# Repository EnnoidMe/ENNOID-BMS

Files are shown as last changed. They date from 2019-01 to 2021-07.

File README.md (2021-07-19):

# ENNOID - BMS

ENNOID-BMS is an open-source configurable battery management system consisting of a Master board based on an STM32 microcontroller connected through an ISOSPI interface to several modular slave boards. ENNOID-BMS can monitor the specifics temperatures, currents & voltages that are critical for any lithium-ion battery packs. Based on the monitored inputs & the configured parameters, the master board can allow or interrupt the flow of energy from the battery pack by switching the state of external heavy-duty contactors. ENNOID-BMS can measure each cell voltage level & can trigger the passive balancing function during charging for cells above the configured limit to ensure that all cells have a similar State-Of-Charge (SOC). Parameters can be configured through the ENNOID-BMS-Tool software running on a USB connected host computer.

## Ordering:

For ordering assembled BMS or battery packs, please visit:

https://www.ennoid.me/bms/gen-1

## Documentation:
https://blog.ennoid.me/

## Block diagram

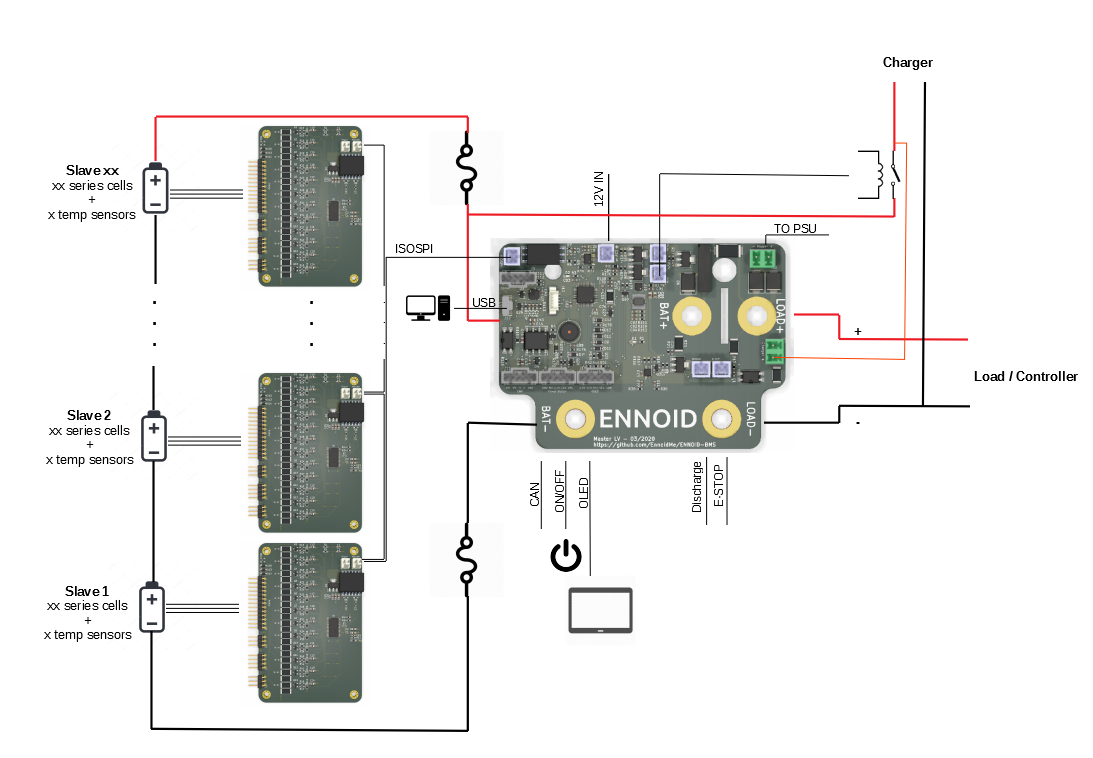
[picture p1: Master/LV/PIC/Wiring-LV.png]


The evolution of the BMS can be followed on this thread:

https://endless-sphere.com/forums/viewtopic.php?f=14&t=92952

## Features:

- Modular with master/slave topology
- 12S, 15S & 18S slaves board options
- Master board options: High Voltage (Master-HV) & Low voltage (Master-LV)
- Up to 500A continuous operation
- Integrated bi-directional current sensor
- 12V drive coil outputs for charge,  discharge & auxiliary circuits
- Communication between slaves & master through a two-wire daisy chained ISOSPI interface
- Isolated CAN bus interface 
- Isolated charger detection circuit
- Voltage measurement for battery pack & load
- Build-in precharge circuits
- USB interface for programming and firmware upgrades through an easy to use graphical user interface
- OLED Display, serial output & power button
- 0V to 5V cell voltage operation

## Documentation:

[ENNOID-BMS Datasheet](https://github.com/EnnoidMe/ENNOID-BMS/blob/master/Datasheet.pdf)

## Software:

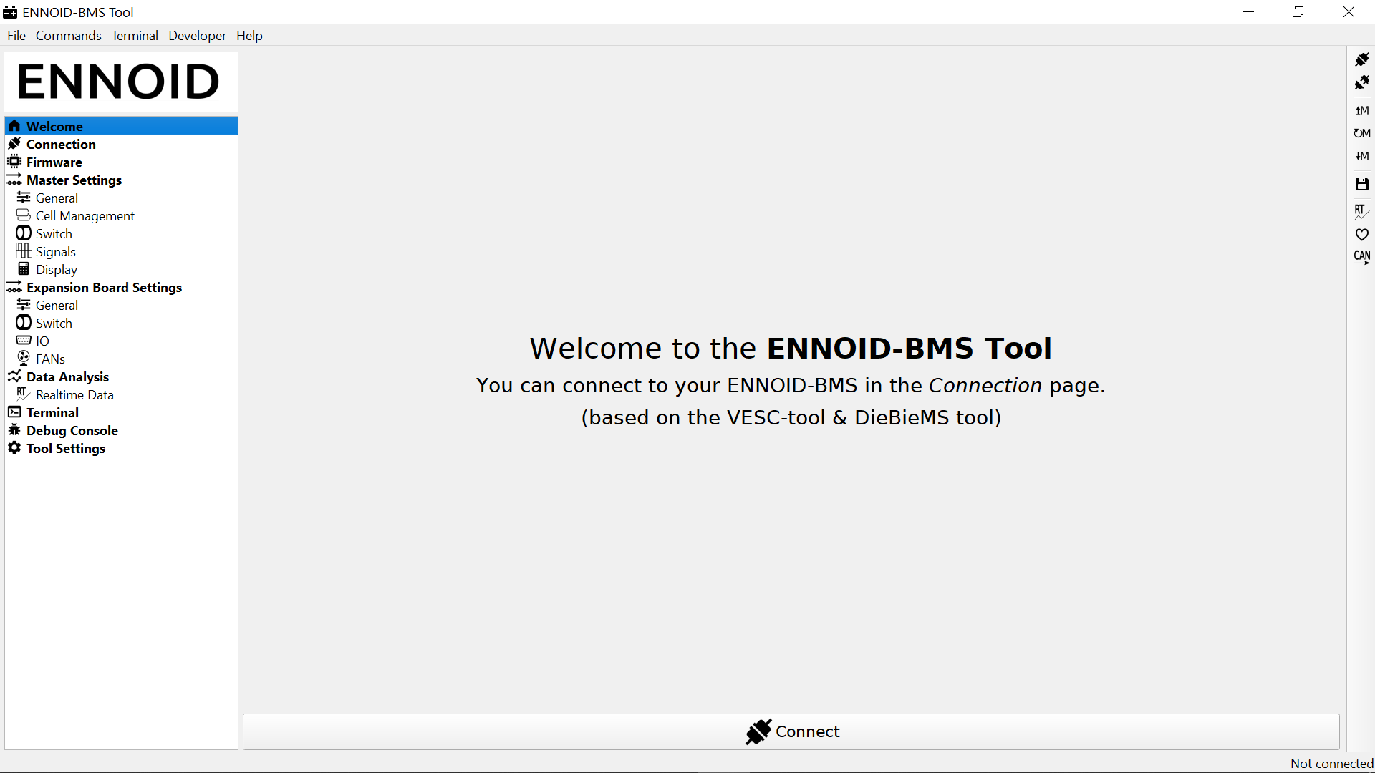
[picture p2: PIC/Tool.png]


ENNOID-BMS GUI configuration tool:
[ENNOID-BMS tool](https://github.com/EnnoidMe/ENNOID-BMS-Tool)

## Firmware:

ENNOID-BMS firmware .bin file:
[ENNOID-BMS.bin](https://github.com/EnnoidMe/ENNOID-BMS-Firmware)

View this project on [CADLAB.io](https://cadlab.io/project/1987).

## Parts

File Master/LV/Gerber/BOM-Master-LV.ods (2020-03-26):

ID | Part | Footprint | MPN | QTY
BZ1 | AI-1027-TWT-5V | ENNOID:BUZZER | AI-1027-TWT-5V-2-R | 1
> C6, C7 | 10n | Capacitor_SMD:C_0603_1608Metric | GRM188R71H103KA01D | 2
C20 | 1u | Capacitor_SMD:C_0603_1608Metric | GRM188R71E105KA12D | 1
> C39, C40, C42, C88 | 2.2u | Capacitor_SMD:C_0603_1608Metric | GRM188R61A225KE34D | 4
> C1, C8, C11, C41, C44, C47, C71-C73, C78, C80-C84 | 100n | Capacitor_SMD:C_0603_1608Metric | GRM188R71E104KA01D | 15
> C43, C46 | 1u | Capacitor_SMD:C_0805_2012Metric | GRM188R71E105KA12D | 2
C45 | 10n | Capacitor_SMD:C_0805_2012Metric | GRM188R71H103KA01D | 1
> C76, C77 | 18p | Capacitor_SMD:C_0603_1608Metric | GRM1885C1H180JA01D | 2
> C89, C90 | 22u | Capacitor_SMD:C_0805_2012Metric | CL21A226MOQNNNE | 2
C91 | 47n | Capacitor_SMD:C_0603_1608Metric | GCM188R71H473KA55D | 1
> C92-C94 | 10u | Capacitor_SMD:C_0603_1608Metric | CL10A106MQ8NNNC | 3
D1 | POWER | LED_SMD:LED_0603_1608Metric | SML-D12P8WT86C | 1
D2 | STATUS | LED_SMD:LED_0603_1608Metric | SML-D12P8WT86C | 1
D3 | SP0502BAHT | TO_SOT_Packages_SMD:SOT-23 | SP0502BAHTG | 1
D4 | SZNUP2105L | TO_SOT_Packages_SMD:SOT-23 | SZNUP2105LT1G | 1
D5 | smcj150ca | Diode_SMD:D_SMC |  | 1
> D7, D10 | BZT52C16 | Diodes_SMD:D_SOD-123 | BZT52C16-E3-08 | 2
> D8, D9, D11-D13 | 1N4148W | Diodes_SMD:D_SOD-123 | 1N4148W-7-F | 5
K1 | HE3621A1200 | ENNOID:HE3621A1200 | HE3621A1200 | 1
L3 | 744043151 | Inductors_SMD:L_Wuerth_WE-PD2-Typ-MS | 744043151 | 1
> Q1, Q3, Q26-Q30 | BSS138 | TO_SOT_Packages_SMD:SOT-23 | BSS138 | 7
> Q4-Q7 | BUK98150-55A | Package_TO_SOT_SMD:SOT-223 | BUK98150-55A/CUF | 4
> R1-R3 | 470 | Resistor_SMD:R_0603_1608Metric | RC0603JR-07470RL | 3
R4 | 1.5k | Resistor_SMD:R_0603_1608Metric | RC0603JR-071K5L | 1
R5 | 806 | Resistor_SMD:R_0603_1608Metric | RC0603JR-071K2L | 1
> R6, R7 | 51 | Resistor_SMD:R_0603_1608Metric | RC0603JR-0751RL | 2
R9 | 100k | Resistor_SMD:R_2512_6332Metric | RC2512FK-07100KL | 1
R11 | 10k | Resistor_SMD:R_2512_6332Metric | 25121WJ0103T4E | 1
> R16, R20 | 220k | Resistor_SMD:R_2512_6332Metric | 25121WF2203T4E | 2
> R21, R170 | 100k | Resistor_SMD:R_0603_1608Metric | RC0603JR-07100KL | 2
> R23-R25, R32 | 10 | Resistor_SMD:R_0603_1608Metric | RC0603JR-0710RL | 4
R29 | CSM2F-8518-L100J01 | ENNOID:CSM2F-8518-L100J01 | CSM2F-8518-L100J01 | 1
R36 | 1.2k | Resistor_SMD:R_0603_1608Metric | RC0603FR-07806RL | 1
> R17, R42, R46, R50, R166, R167 | 4.75k | Resistor_SMD:R_0603_1608Metric | RC0603JR-074K7L | 6
> R111, R112 | 240 | Resistor_SMD:R_0603_1608Metric | RC0603FR-07240RL | 2
> R19, R113, R114, R168, R173, R176, R178 | 10k | Resistor_SMD:R_0603_1608Metric | RMCF2512JT10K0 | 7
R115 | 4.7M | Resistor_SMD:R_0805_2012Metric | RC0805JR-0710ML | 1
> R37, R116 | 2.2k | Resistor_SMD:R_0603_1608Metric | RC0603JR-072K2L | 2
> R35, R38, R172 | 100 | Resistor_SMD:R_0603_1608Metric | RC0603FR-07100RL | 3
R174 | 1M | Resistor_SMD:R_0603_1608Metric | RC0603JR-071ML | 1
> R8, R27, R28, R33, R175, R177 | 4.7M | Resistor_SMD:R_0603_1608Metric | RC0603FR-074M7L | 6
R179 | 130k | Resistor_SMD:R_0603_1608Metric | RC0603FR-07130KL | 1
> R180-R182 | 1 | Resistor_SMD:R_0603_1608Metric | RC0603FR-071RL | 3
TH1 | Thermistor_NTC 100k | Resistor_SMD:R_0805_2012Metric | SDNT2012X104F4250FTF | 1
TR2 | HM2108NL | ENNOID:HM2108NL | HM2108NL | 1
U1 | ISL28022 | Package_SO:VSSOP-10_3x3mm_P0.5mm | ISL28022FUZ-T7A | 1
U2 | LTC6820 | Housings_SSOP:MSOP-16_3x4mm_Pitch0.5mm | LTC6820IMS#PBF | 1
U5 | SFH617A-2X009T | Housings_DIP:SMDIP-4_W9.53mm_Clearance8mm | SFH617A-2X009T | 1
U7 | CP2104 | Housings_DFN_QFN:QFN-24-1EP_4x4mm_Pitch0.5mm | CP2104-F03-GM | 1
U8 | ISO1050DUBR | ENNOID:ISO1050 | ISO1050DUBR | 1
U9 | SFH617A-2X017T | Housings_DIP:SMDIP-4_W9.53mm_Clearance8mm | SFH617A-2X009T | 1
U17 | STM32F303CCTx | Housings_QFP:LQFP-48_7x7mm_Pitch0.5mm | STM32F303CCT6 | 1
U19 | LM5165YDRC | Housings_SON:Texas_S-PVSON-N10_ThermalVias | LM5165YDRCT | 1
Y1 | 8MHz | Crystals:Crystal_SMD_Abracon_ABM3-2pin_5.0x3.2mm | ABM3-8.000MHZ-D2Y-T | 1

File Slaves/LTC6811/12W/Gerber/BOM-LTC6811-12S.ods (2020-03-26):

ID | Part | Footprint | MPN | QTY
> C1, C2, C5, C25, C26 | 1u | Capacitor_SMD:C_0805_2012Metric | CL21B105KBFNNNE | 5
> C3, C4, C8-C24 | 100n | Capacitor_SMD:C_0603_1608Metric | CC0603KRX7R0BB104 | 19
> C6, C7 | 100p | Capacitor_SMD:C_0603_1608Metric | CL10C101JB8NNNC | 2
> D1-D12 | PDZ7.5B | Diode_SMD:D_SOD-323 | PDZ7.5BZ | 12
> D13, D14 | 1N4148W | Diode_SMD:D_SOD-123 | 1N4148W-7-F | 2
D15 | BZT52H-C62 | Diode_SMD:D_SOD-123 | BZT52H-C62,115 | 1
D16 | LED | LED_SMD:LED_0603_1608Metric | SML-D12P8WT86C | 1
> F1-F13 | 0.25A | ENNOID:FUSE | N/A | 13
FB1 | 33 | Resistor_SMD:R_0603_1608Metric | BLM18PG330SN1D | 1
J1 | Cells | Pin_Headers:Pin_Header_Angled_1x13_Pitch2.54mm | N/A | 1
J2 | PB MB | ENNOID:Pin_1x02-XL | 70543-0001 | 1
J3 | PA MA | ENNOID:Pin_1x02-XL | 70543-0001 | 1
J4 | Temp | Connector_PinHeader_2.54mm:PinHeader_1x05_P2.54mm_Horizontal | N/A | 1
> J5-J8 | Conn_01x01 | Mounting_Holes:MountingHole_3.2mm_M3_ISO7380_Pad | N/A | 4
LOGO1 | Logo_Open_Hardware_Small | ENNOID:ENNOID-LOGO | N/A | 1
Q1 | NSV1C201MZ4 | TO_SOT_Packages_SMD:SOT-223 | NSV1C201MZ4T1G | 1
> Q2-Q13 | TSM2323 | TO_SOT_Packages_SMD:SOT-23 | TSM2323CX RFG | 12
> R3, R10 | 1.2k | Resistor_SMD:R_0603_1608Metric | RC0603JR-071K2L | 2
R4 | 806 | Resistor_SMD:R_0603_1608Metric | RC0603FR-07806RL | 1
> R1, R2, R5, R6, R13, R16, R19, R22, R25, R28, R31, R34, R37, R40, R43, R46 | 100 | Resistor_SMD:R_0603_1608Metric | RC0603FR-07100RL | 16
R7 | 1M | Resistor_SMD:R_0603_1608Metric | RC0603JR-071ML | 1
> R8, R9 | 0 | Resistor_SMD:R_0603_1608Metric | RC0603JR-070RL | 2
> R11, R60-R63 | 100k | Resistor_SMD:R_0603_1608Metric | RC0603JR-07100KL | 5
> R12, R15, R18, R21, R24, R27, R30, R33, R36, R39, R42, R45 | 36 | Resistor_SMD:R_2512_6332Metric | RTT25360JTE | 12
> R14, R17, R20, R23, R26, R29, R32, R35, R38, R41, R44, R47 | 3.3k | Resistor_SMD:R_0603_1608Metric | RC0603JR-073K3L | 12
TH1 | 100k | Resistor_SMD:R_0805_2012Metric | SDNT2012X104F4250FTF | 1
TR1 | HM2102NL | ENNOID:HM2102NL | HM2102NLT | 1
U1 | LTC6811-1 | Housings_SSOP:TSSOP-48_6.1x12.5mm_Pitch0.5mm | LTC6811HG-1#PBF | 1

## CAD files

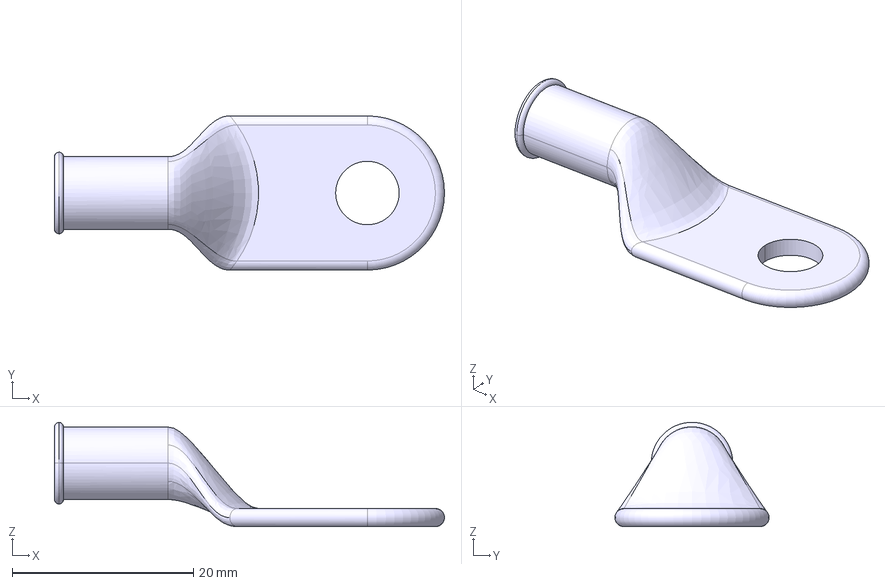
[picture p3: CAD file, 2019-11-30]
Master/LV/PCB/CAD/Copper_Lug.stp
43.0 x 17.0 x 11.5 mm

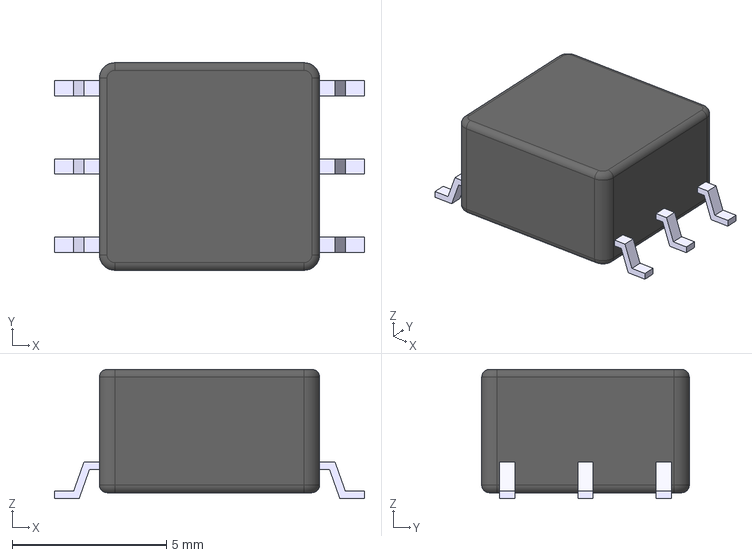
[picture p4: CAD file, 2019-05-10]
Master/LV/PCB/CAD/WURTH-760390014.stp
10.1 x 6.73 x 4.19 mm

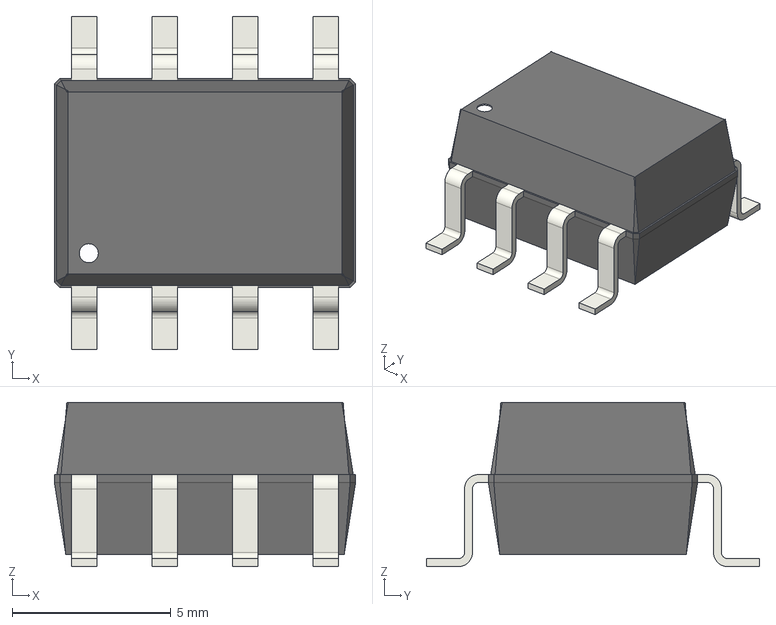
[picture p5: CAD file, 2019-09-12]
Master/HV/PCB/CAD/soic_8_66x95_p254.step
9.50 x 10.5 x 5.18 mm

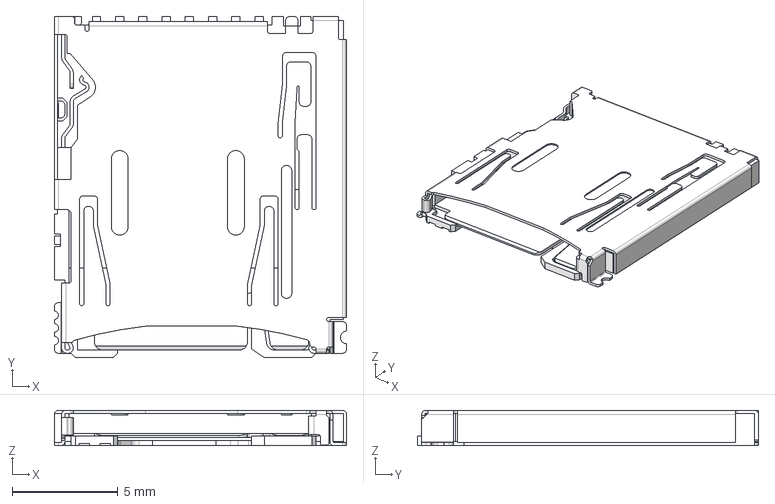
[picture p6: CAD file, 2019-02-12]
Master/LV/PCB/CAD/DM3AT-SF-PEJM5.stp
13.8 x 16.2 x 1.68 mm

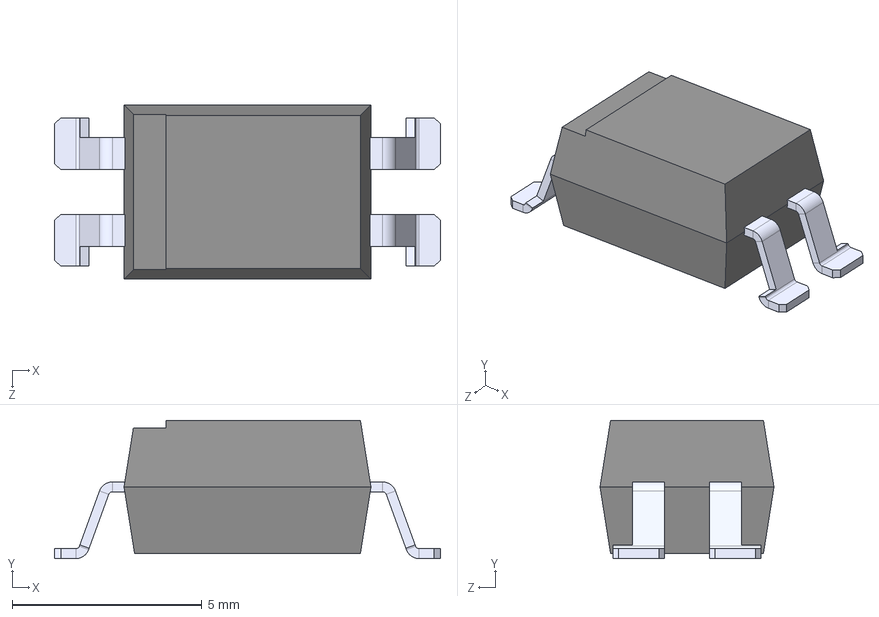
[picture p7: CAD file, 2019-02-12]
Master/LV/PCB/CAD/DIP4-OP9.STEP
10.2 x 3.64 x 4.58 mm

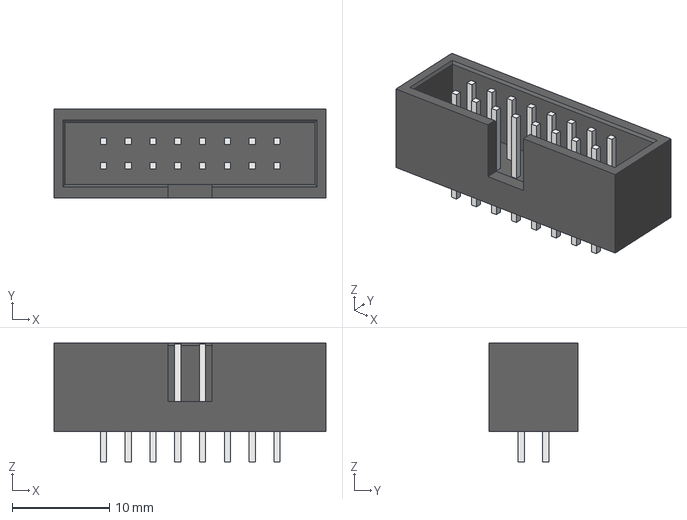
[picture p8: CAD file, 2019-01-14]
Master/LV/PCB/CAD/CONN 2X8.step
27.9 x 9.10 x 12.2 mm

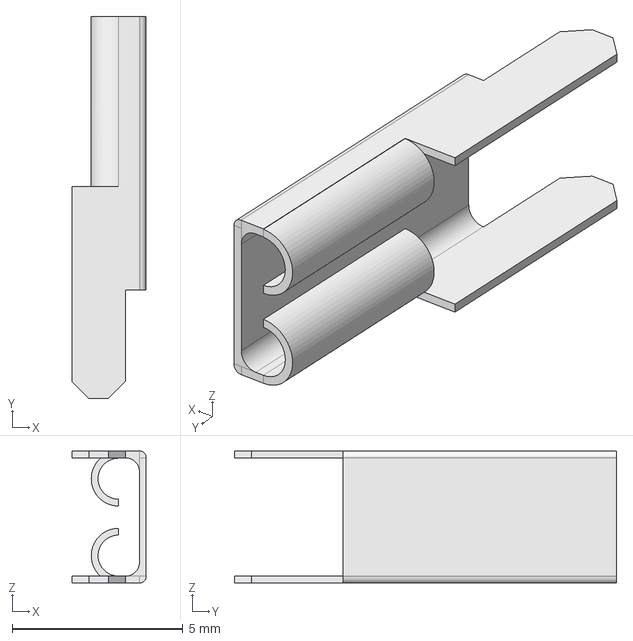
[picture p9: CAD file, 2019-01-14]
Master/LV/PCB/CAD/Spade.step
2.18 x 11.2 x 3.86 mm

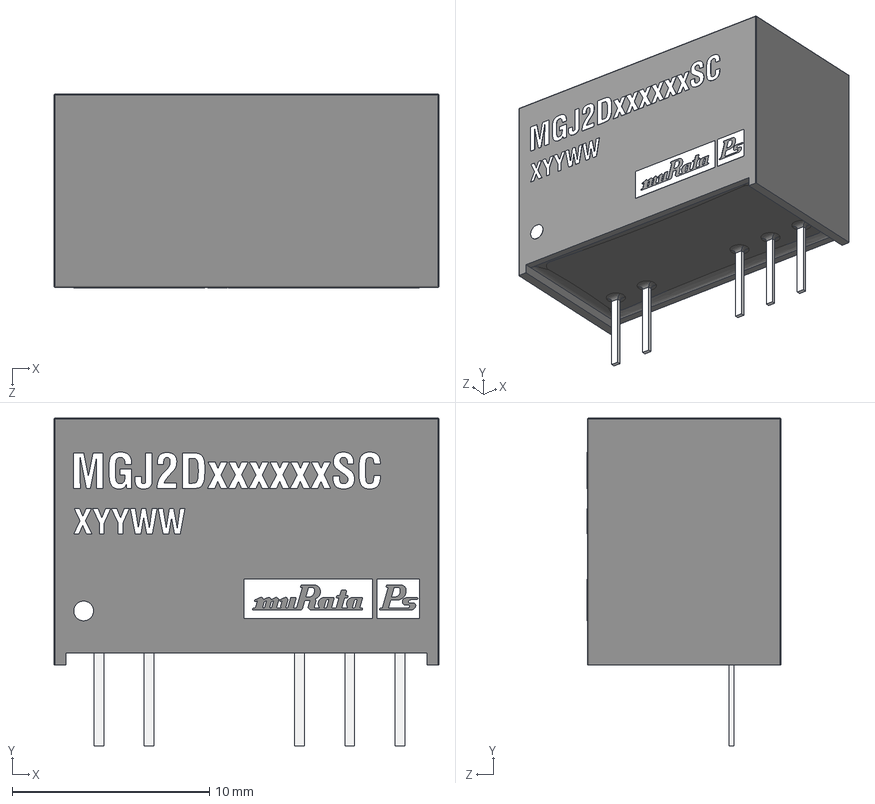
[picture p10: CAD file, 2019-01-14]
Master/HV/PCB/CAD/MGJ2.step
19.5 x 16.6 x 9.82 mm

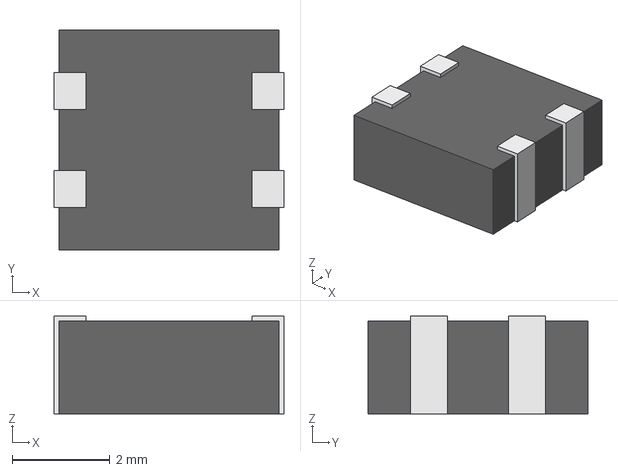
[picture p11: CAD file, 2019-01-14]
Master/LV/PCB/CAD/ACM4520.step
4.70 x 4.50 x 2.00 mm

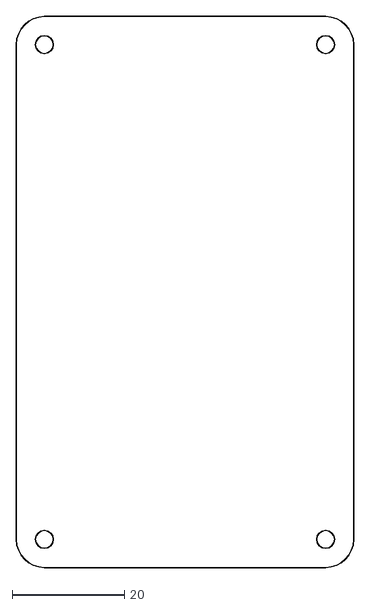
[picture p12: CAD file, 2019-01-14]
Master/HV/PCB/CAD/Kepp_OUT.dxf
60.0 x 98.0

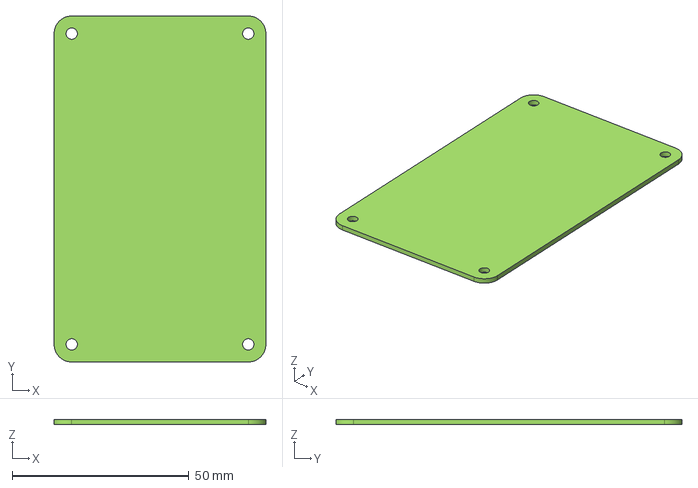
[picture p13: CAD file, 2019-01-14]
Master/LV/PCB/CAD/Keep_OUT.fcstd
60.0 x 98.0 x 1.50 mm

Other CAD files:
Master/HV/PCB/CAD/1051330001.stp
Master/HV/PCB/CAD/70543-0001.stp
Master/HV/PCB/CAD/705430004.stp
Master/HV/PCB/CAD/ACM4520.fcstd
Master/HV/PCB/CAD/AMC1301.fcstd
Master/HV/PCB/CAD/AMC1301.step
Master/HV/PCB/CAD/COMPOUND.CATPart
Master/HV/PCB/CAD/COMPOUND_1.CATPart
Master/HV/PCB/CAD/CONN 2x8.fcstd
Master/HV/PCB/CAD/HM2108NL.CATPart
Master/HV/PCB/CAD/SOLID.CATPart
Master/HV/PCB/CAD/SOLID_1.CATPart
Master/HV/PCB/CAD/SOLID_10.CATPart
Master/HV/PCB/CAD/SOLID_11.CATPart
Master/HV/PCB/CAD/SOLID_12.CATPart
Master/HV/PCB/CAD/SOLID_13.CATPart
Master/HV/PCB/CAD/SOLID_2.CATPart
Master/HV/PCB/CAD/SOLID_3.CATPart
Master/HV/PCB/CAD/SOLID_4.CATPart
Master/HV/PCB/CAD/SOLID_5.CATPart
Master/HV/PCB/CAD/SOLID_6.CATPart
Master/HV/PCB/CAD/SOLID_7.CATPart
Master/HV/PCB/CAD/SOLID_8.CATPart
Master/HV/PCB/CAD/SOLID_9.CATPart
Master/HV/PCB/CAD/Spade.fcstd
Master/HV/PCB/CAD/mgj2.fcstd
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

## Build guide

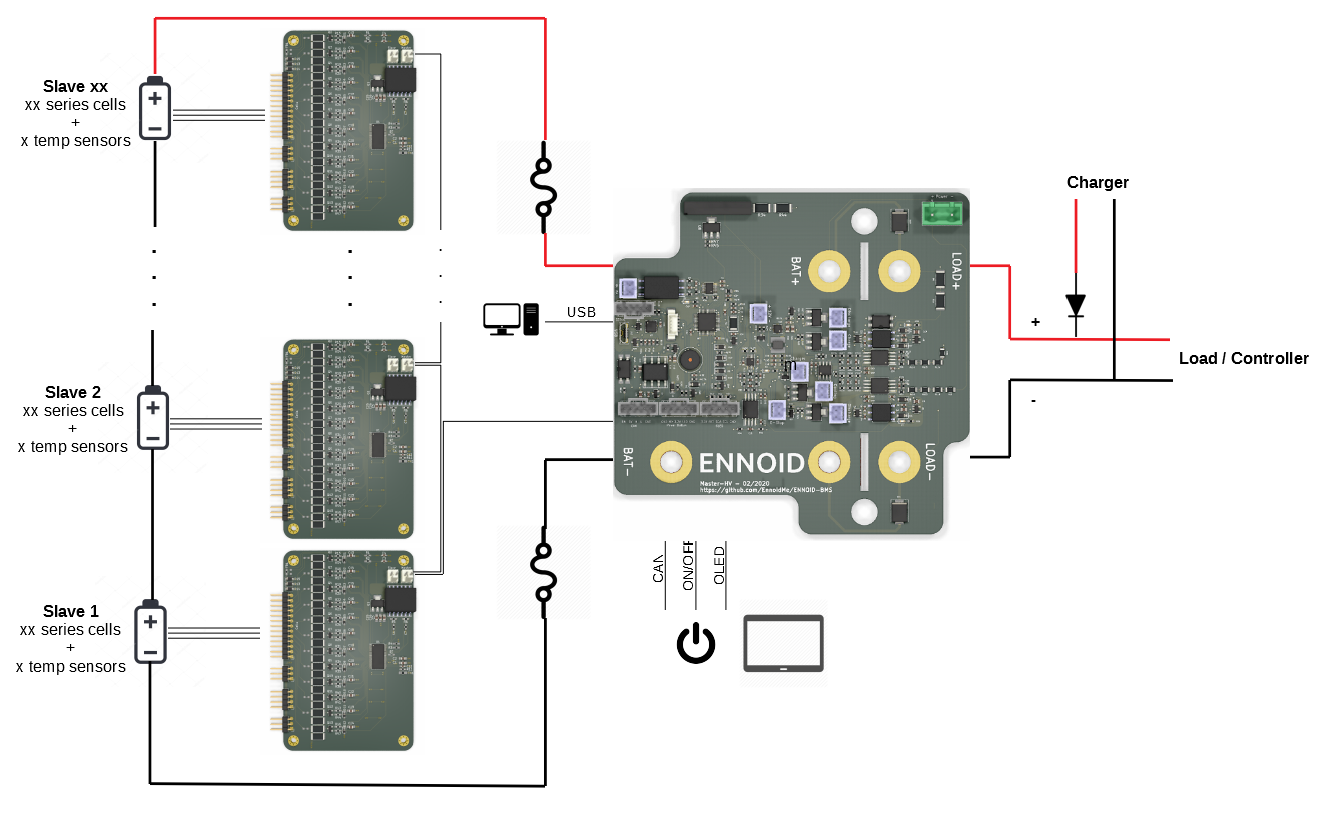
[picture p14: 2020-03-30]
Master/HV/PIC/Wiring-HV.png

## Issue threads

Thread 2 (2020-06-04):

One of the battery is not detected.

raviatnunam, 2020-06-04:
I have made one 6s1p pack to perform test on ENNOID BMS using Master-05/2019 and slave LT6811-05/2018. The issue I'm facing from last one month is whenever i connect 6s or 7s or any configuration Software shows -1 cell in its Real time data window. I tried to debug hardware i didn't find any issues as of now.

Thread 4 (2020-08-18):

MCU code/SPI driver

hachimbala, 2020-08-18:
Hi,

I want to make some changes at the SPI communication, please could you give me the MCU software project, or at least the library used to drive the LTC6820 with daisy chained LTC6813's

Thank you so much
Best regards

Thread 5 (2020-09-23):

Code compiling

Jahnavi-pinnamaneni, 2020-09-23:
Hi!
I want to compile and build the code. Hence, may I know the procedure for the same?

Thank you
Jahnavi

EarthLord, 2020-11-30:
These are KiCad files.You'll need the KiCad PCB design suite for this.

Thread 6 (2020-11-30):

Layout files are missing

EarthLord, 2020-11-30:
Hello, thanks for this open source project. Would you be providing the .kicad_pcb files for the layout as they are missing you?

Regards, Prithvi

zwn, 2023-01-20:
https://endless-sphere.com/forums/viewtopic.php?f=14&t=92952&start=325#p1688078

> Schematics on github are quite outdated. I stopped to make newest designs open source.
>
> Firmware & software are still open source so you can use it. They do represent 90% of the work, Hardware design is only a small part.

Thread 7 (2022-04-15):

Firmware update problem

Kabron287, 2022-04-15:
Hello,
I already post this message to
https://endless-sphere.com/forums/viewtopic.php?f=14&t=92952&start=350
but did not receive the answer.

I compiled and uploaded BMS FW to NUCLEO-F303RE for testing.
Seems that everything fine, but after updating FW version does not changing.
While sniffing serial communication I do see the upgrade process as transfering FW data packets, but obviously it does not finished successfuly.
Could you, please, explain what happened?
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

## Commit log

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2018-07-10 Switch to LTC6813 IC
    BQ76PL455A has no SPI and new gen LTC6813 seems superior
    [Analog_Inputs.sch, BMS-Interface_Interface.sch, BMS-Master.kicad_pcb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]
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2019-01-06 Bootloader from DieBieMS added
    [MCU.sch, wireless.sch]
2019-01-06 Schematics 99% completed
    Only need to review everything &
    [BMS-Master.sch, PowerSupply.sch, cell.sch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]
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2019-01-06 Contactor outputs don't need ISO
    [switches.sch]
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2019-01-11 Now master & slave are on separate boards
    [BMS-Master.kicad_pcb, BMS-Master.sch, MCU.sch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]
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2019-01-11 Separating slave from master
    Schematics & PCB changes
    [250-1109-rev1.step, BAS-M-R0002.step, BMS-Master.kicad_pcb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]
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2019-01-11 components placed on PCB
    [BMS-Master.kicad_pcb, BMS-Master.sch, CAN.sch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]
2019-01-12 Ditching 400V PSU
    contactors need more amo than possible to deliver
    [BMS-Master.kicad_pcb, BMS-Master.sch, PowerMonitor.sch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]
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2019-01-13 PCB master 50% completed
    [BMS-Master.kicad_pcb, BMS-Master.sch, PowerMonitor.sch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]
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2019-01-14 PCB update master final
    [BMS-Master.kicad_pcb, MCU.sch, _saved_MCU.sch]
2019-01-15 Master schematics & PCB updated
    [BMS-Master.kicad_pcb, PowerMonitor.sch]
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2019-01-15 Slave PCB placement update
    [BMS-Slave.kicad_pcb, _saved_BMS-Slave.sch, cell.sch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]
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2019-01-16 Ennoid LOGO added slave & master
    [BMS-Master.kicad_pcb, BMS-Master.sch, BMS-Slave.kicad_pcb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]
2019-01-16 Mistake correction in master with LTC6820
    [MCU.sch]
2019-01-16 Master major PCB change
    [BMS-Master.kicad_pcb, MCU.sch, _saved_BMS-Master.sch]
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2019-01-28 slave ltc6813 vias added to cool down
    [BMS-Slave.kicad_pcb]
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2019-03-05 LTC6811 added diode protection inputs
    [250-1109-rev1.step, BAS-M-R0002.step, DF13-4P-1.25H.stp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]
2019-03-05 temperatures sensors now has separate grounds
    [LTC6811-B_Cu.gbr, LTC6811-B_Mask.gbr, LTC6811-B_Paste.gbr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]
2019-03-06 Small changes on master
    Possible now to bypass isolation & PSU if only one slave is used.
    [BMS-Master.kicad_pcb, BMS-Master.sch, PowerMonitor.sch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]
2019-03-06 moved usb port 1mm
    [BMS-Master.kicad_pcb]
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2019-03-08 LTC6811 is now 2W per level
    [LTC6811-B_Cu.gbr, LTC6811-B_Mask.gbr, LTC6811-B_Paste.gbr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]
2019-03-15 mistake correction in layout USB power
    [BMS-Master (LAPTOP-FSV2IKVR's conflicted copy 2019-03-06).kicad_pcb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]
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2019-03-20 Removing some old concepts images
    [BOM.ods]
2019-04-29 New buzzer, new connector & mistake correction
    [250-1109-rev1.step, BAS-M-R0002.step, BMS-Master.kicad_pcb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]
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2019-05-01 Update current sensor connector + LTC6811
    [LTC6811.kicad_pcb, LTC6811.sch, current_sensor.kicad_pcb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]
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2019-05-07 LTC6811 now more compact
    [250-1109-rev1.step, BAS-M-R0002.step, DF13-4P-1.25H.stp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]
2019-05-09 VBUS PCB mistake corrected
    [BMS-Master.kicad_pcb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]
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2019-05-10 schematics major improvement by removing bq76200
    [250-1109-rev1.step, BAS-M-R0002.step, BMS-Master.kicad_pcb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]
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2019-05-13 LTC6811 schematics mistake correction
    [250-1109-rev1.step, BAS-M-R0002.step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]
2019-05-27 Charge detect resistor in master PCB now 1W power dissipation
    [BMS-Master.kicad_pcb, LTC6811.kicad_pcb, LTC6811.sch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]
2019-05-27 master Charge detect resistor update now 1W power dissipation
    [BMS-Master.sch, CAN.sch, MCU.sch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]
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2019-06-02 charge port protection added
    [250-1109-rev1.step, BAS-M-R0002.step, BMS-Master.kicad_pcb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]
2019-06-02 Charge detect circuit update
    [BMS-Master.kicad_pcb, BMS-Master.sch, CAN.sch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]
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2019-06-26 Readme update with wiring schematic
    [BMS-Master.sch, CAN.sch, LTC6811.sch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]
2019-06-30 LTC6820 miso resistor value changed
    [LTC6811.sch, MCU.sch, switches.sch]
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2019-07-17 LTC6811 even more compact
    [BMS-Master-B_Cu.gbr, BMS-Master-B_Mask.gbr, BMS-Master-B_SilkS.gbr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]
2019-08-03 Latest gerber & readme
    [BMS-Master-B_Cu.gbr, BMS-Master-B_Mask.gbr, BMS-Master-B_SilkS.gbr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]
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2019-08-09 Current sensing & charge detect improvements
    [PowerMonitor.sch]
2019-08-10 Current sensors updates & master
    [250-1109-rev1.step, BAS-M-R0002.step, CAN.sch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]
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2019-08-20 PSU update & new details in schematics
    [BMS-Master.sch, PSU.sch, PowerMonitor.sch]
2019-08-27 Readme update
    No more sd card & wireless options
    [PSU.sch]
2019-09-02 LTC6812 & LTC6813 update
    [LTC6812.sch, MCU.sch, cell.sch]
2019-09-04 LTC6812 12W & 24W versions
    [LTC6812-12W.sch, LTC6812.sch, cell.sch]
2019-09-12 merged current sensor & precharge circuit into master PCB
    new Cooling output
    [BAS-M-R0002.step, BMS-Master.sch, CAN.sch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]
2019-09-13 Now with integrated precharge & current sensor mount
    [BMS-Master.sch, PowerMonitor.sch, switches.sch]
2019-09-18 Added charger detect from 12V charger Aux
    [PowerSupply.sch]
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2019-11-02 Datasheet update for V1.0
    [BMS-Master.sch, CAN.sch, LTC6811.sch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]
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2020-02-08 Small changes to resistor & connectors
    Now with vertical USB connectors & clip connectors
    [1051330001.stp, BMS-Master-LV.sch, BMS-Master.sch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]
2020-03-01 Schematics updates & improvements
    [BMS-Master-LV.sch, BMS-Master.sch, LTC6811-12W BOM.xlsx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]
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2020-03-26 Minor changes to charging detect circuit for external relay
    [BMS-Master-LV.sch, BOM-LTC6811-12S.ods, BOM-Master-LV.ods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]
2020-03-30 New parts for precharge circuit
    [BMS-Master-LV.sch, BMS-Master.sch, PowerMonitor.sch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]
2020-03-30 Schematic Master-HV minor change
    DischargeNeg has been switched to precharge for better code compatibility
    [MCU.sch, PowerMonitor.sch]
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
